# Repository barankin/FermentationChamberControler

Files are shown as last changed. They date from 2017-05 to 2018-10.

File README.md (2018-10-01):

# Fermentation Chamber Controller
arduino based fermentation chamber temperature controller

* Stage one including:
 * Arduino Nano
 * 1602 LCD display
 * Rotary encoder for changing temperature
 * Two temperature probes DS18B20 using one wire bus
 * Relay for turning compressor on and off
 * Relay for turning heater on and off
* Stage two including:
 * Logging using ESP-01 and Ai Thinker commands over hardware serial
* Stage three including:
 * Full control and status via ESP-01

# Background
* The LCD circuit for the LCD HelloWorld. We will use the same pin configuration:
 * LCD RS pin to digital pin 12
 * LCD Enable pin to digital pin 11
 * LCD D4 pin to digital pin 5
 * LCD D5 pin to digital pin 4
 * LCD D6 pin to digital pin 3
 * LCD D7 pin to digital pin 2
 * LCD R/W pin to ground
 * LCD VSS pin to ground
 * LCD VCC pin to 5V
 * 10K resistor:
 * ends to +5V and ground
 * wiper to LCD VO pin (pin 3)

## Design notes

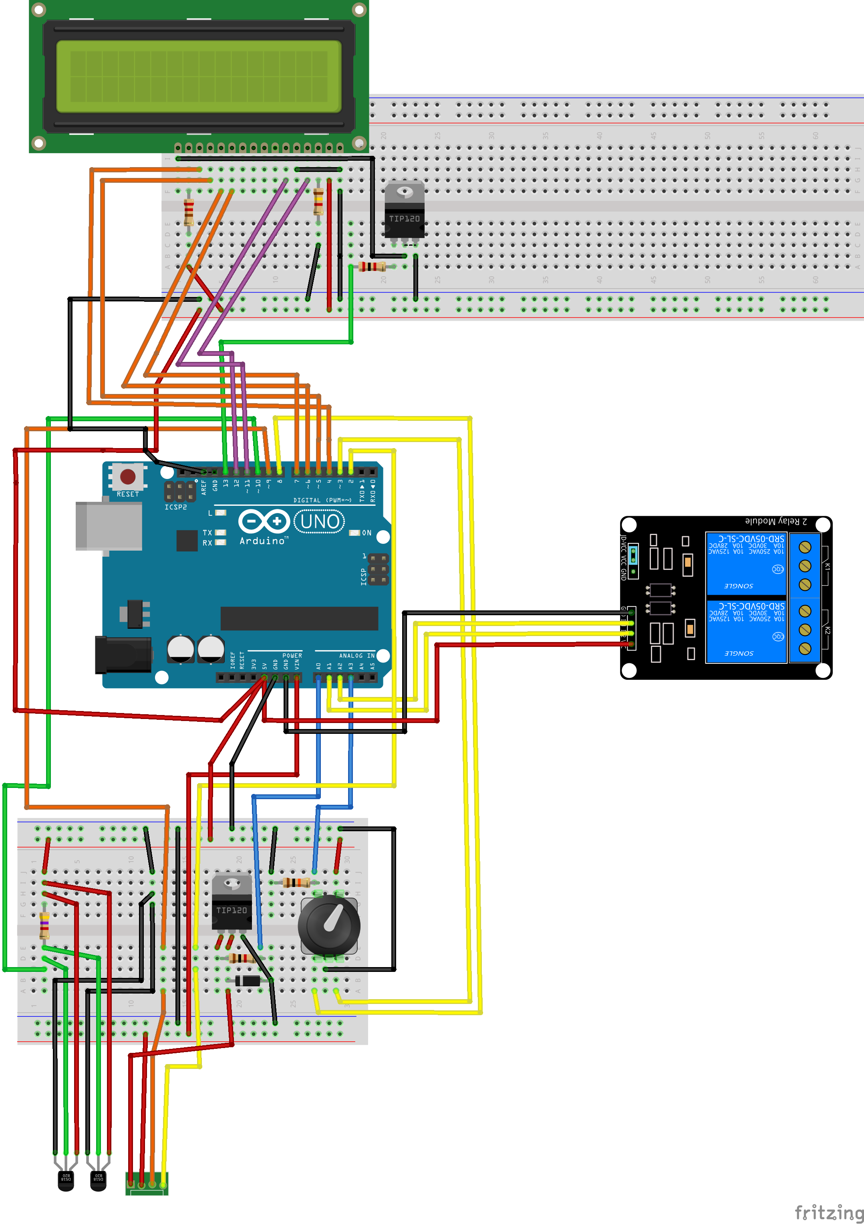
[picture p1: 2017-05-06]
FermentationChamberController_bb.png

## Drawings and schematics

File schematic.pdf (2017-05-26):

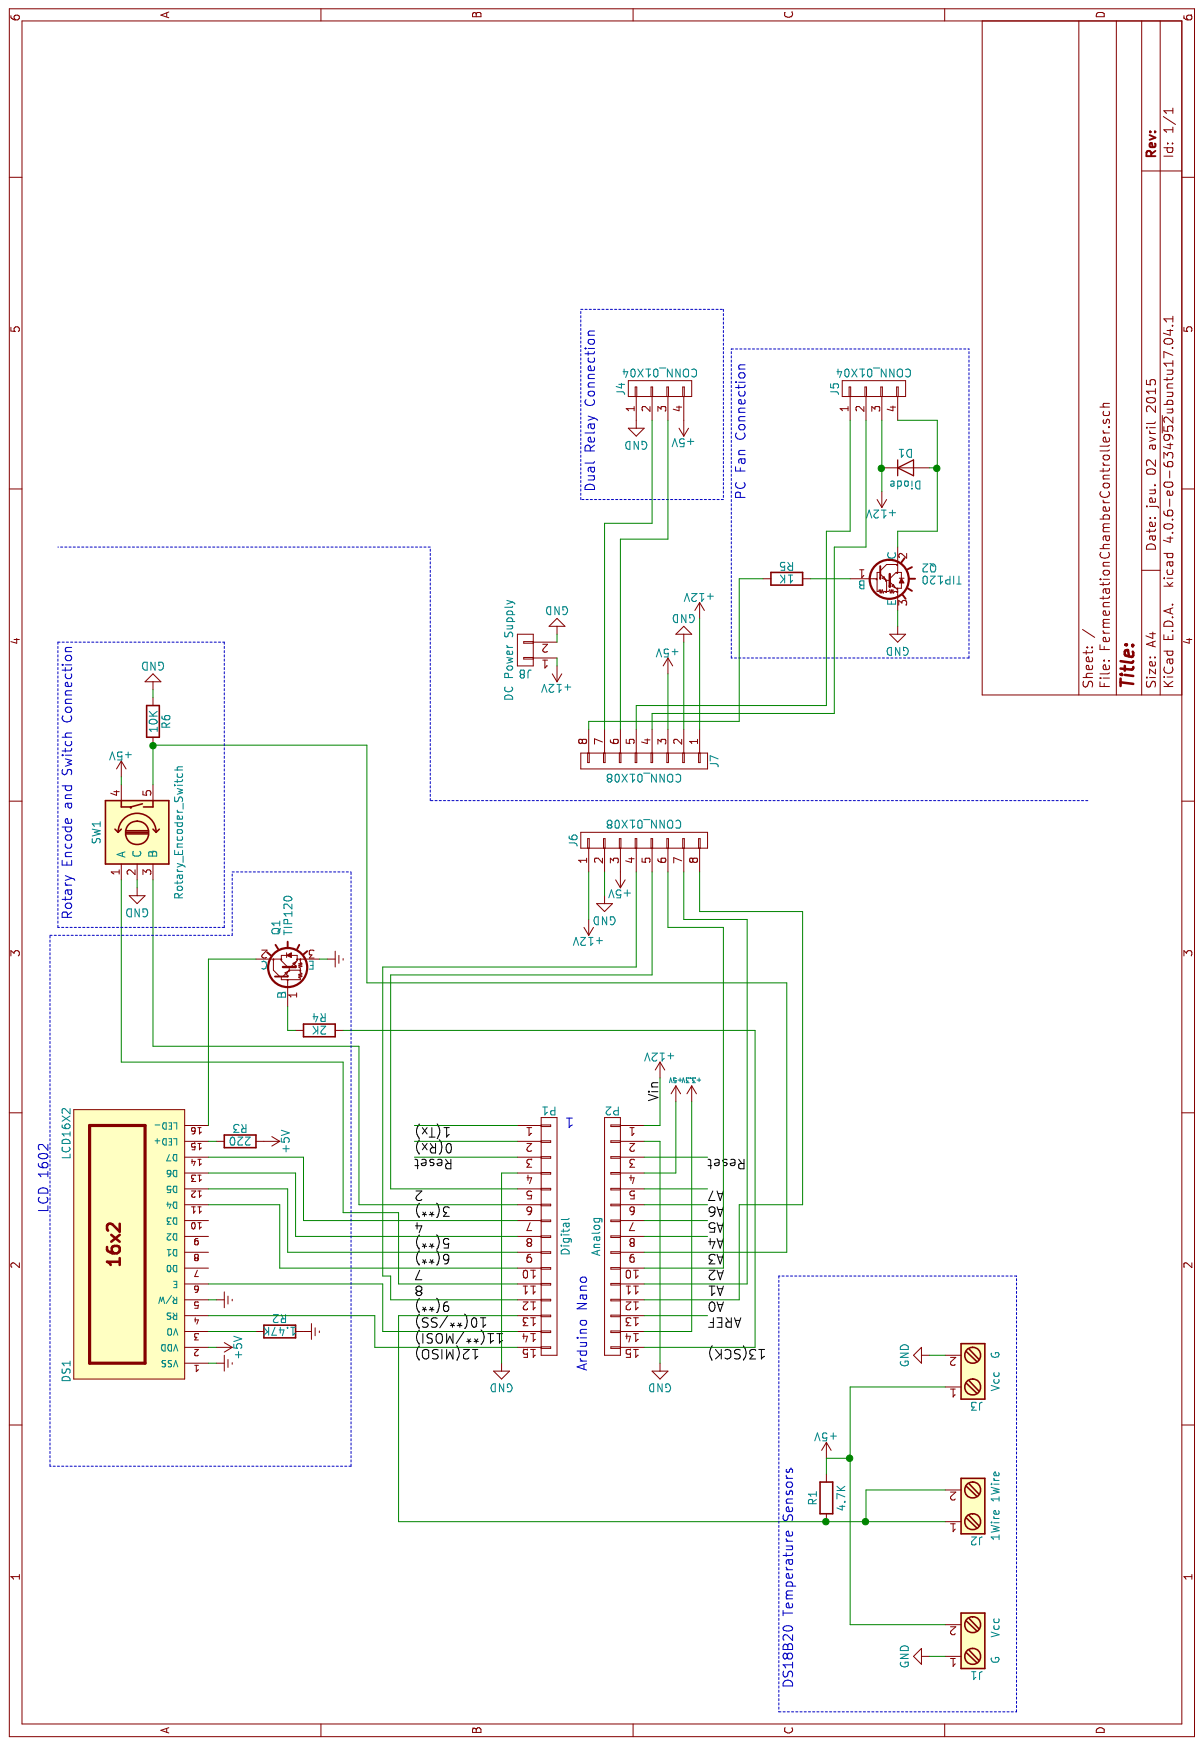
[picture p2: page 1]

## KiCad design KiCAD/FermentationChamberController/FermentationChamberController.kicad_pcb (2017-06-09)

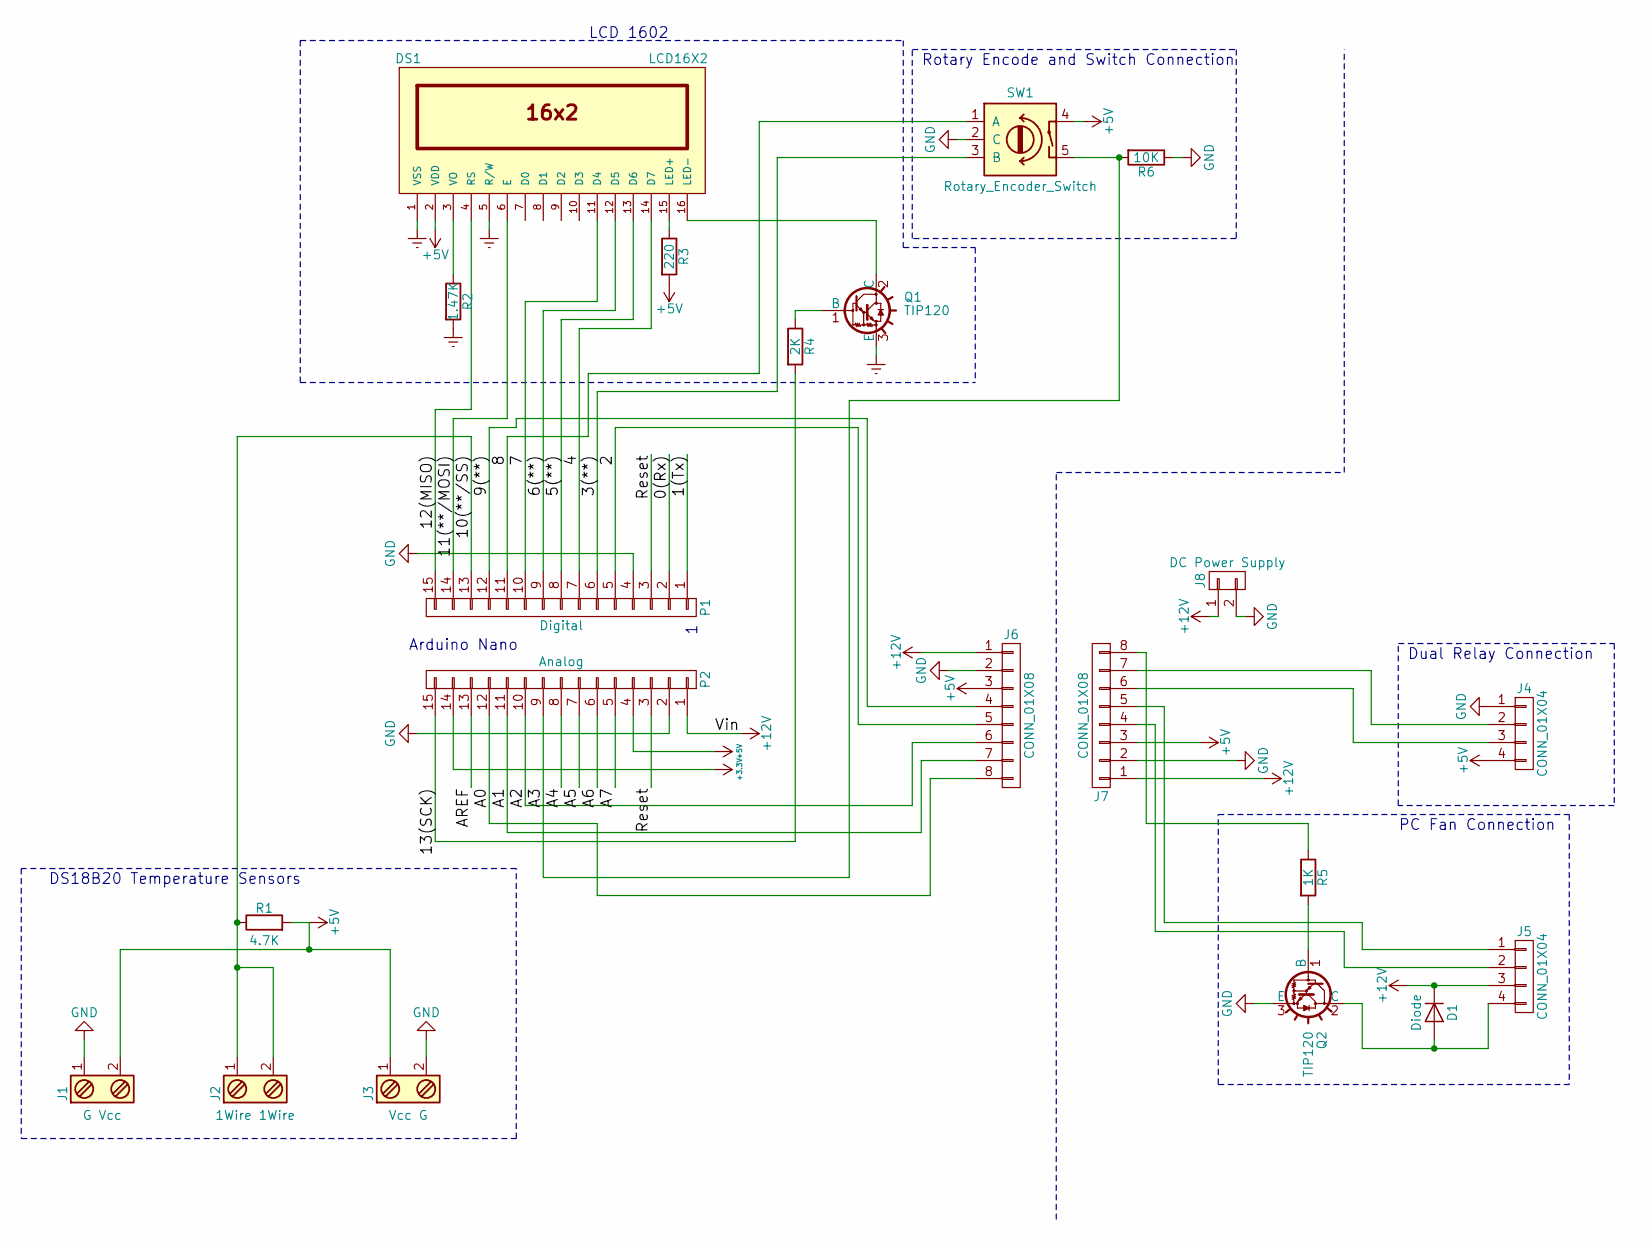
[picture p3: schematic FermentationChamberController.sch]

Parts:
D1: Diode; D_DO-15_P10.16mm_Horizontal
DS1: LCD16X2; Pin_Header_Straight_1x16_Pitch2.54mm
J1: G Vcc; bornier2
J2: 1Wire 1Wire; bornier2
J3: Vcc G; bornier2
J4, J5: CONN_01X04; Pin_Header_Straight_1x04_Pitch2.54mm
J6, J7: CONN_01X08; RJ45_8
J8: DC Power Supply; Pin_Header_Straight_1x02_Pitch1.27mm
P1: Digital; Pin_Header_Straight_1x15_Pitch2.54mm
P2: Analog; Pin_Header_Straight_1x15_Pitch2.54mm
Q1: TIP120; TO-220_Horizontal
Q2: TIP120; TO-220_Vertical
R1: 4.7K; R_Axial_DIN0207_L6.3mm_D2.5mm_P10.16mm_Horizontal
R2: 1.47K; R_Axial_DIN0207_L6.3mm_D2.5mm_P10.16mm_Horizontal
R3: 220; R_Axial_DIN0207_L6.3mm_D2.5mm_P10.16mm_Horizontal
R4: 2K; R_Axial_DIN0207_L6.3mm_D2.5mm_P10.16mm_Horizontal
R5: 1K; R_Axial_DIN0207_L6.3mm_D2.5mm_P10.16mm_Horizontal
R6: 10K; R_Axial_DIN0207_L6.3mm_D2.5mm_P10.16mm_Horizontal
SW1: Rotary_Encoder_Switch; Pin_Header_Straight_1x05_Pitch2.54mm

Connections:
+3V3: P2.14
+5V: DS1.2 (VDD), J1.2, J3.1, J4.4, J6.3, J7.3, P2.4, R1.2, R3.2, SW1.4
+12V: D1.1 (K), J5.3, J6.1, J7.1, J8.1, P2.1
/0(Rx): P1.2
/1(Tx): P1.1
/2: J6.5, P1.5
/3(**): P1.6, SW1.3 (B)
/4: DS1.14 (D7), P1.7
/5(**): DS1.13 (D6), P1.8
/6(**): DS1.12 (D5), P1.9
/7: DS1.11 (D4), P1.10
/8: P1.11, SW1.1 (A)
/9(**): J6.4, P1.12
/10(**/SS): J2.1, J2.2, P1.13, R1.1
/11(**/MOSI): DS1.6 (E), P1.14
/12(MISO): DS1.4 (RS), P1.15
/13(SCK): P2.15, R4.2
/A0: J6.8, P2.12
/A1: J6.7, P2.11
/A2: J6.6, P2.10
/A3: P2.9, R6.2, SW1.5
/A4: P2.8
/A5: P2.7
/A6: P2.6
/A7: P2.5
/AREF: P2.13
/Reset: P1.3, P2.3
Earth: DS1.1 (VSS), DS1.5 (R/W), Q1.3 (E), R2.2
GND: J1.1, J3.2, J4.1, J6.2, J7.2, J8.2, P1.4, P2.2, Q2.3 (E), R6.1, SW1.2 (C)
unnamed: D1.2 (A), J5.4, Q2.2 (C)
unnamed: DS1.3 (VO), R2.1
unnamed: DS1.15 (LED+), R3.1
unnamed: DS1.16 (LED-), Q1.2 (C)
unnamed: J4.2, J7.7
unnamed: J4.3, J7.6
unnamed: J5.1, J7.5
unnamed: J5.2, J7.4
unnamed: J7.8, R5.1
unnamed: Q1.1 (B), R4.1
unnamed: Q2.1 (B), R5.2

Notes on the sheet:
LCD 1602
DS18B20 Temperature Sensors
PC Fan Connection
Dual Relay Connection
Rotary Encode and Switch Connection
Arduino Nano

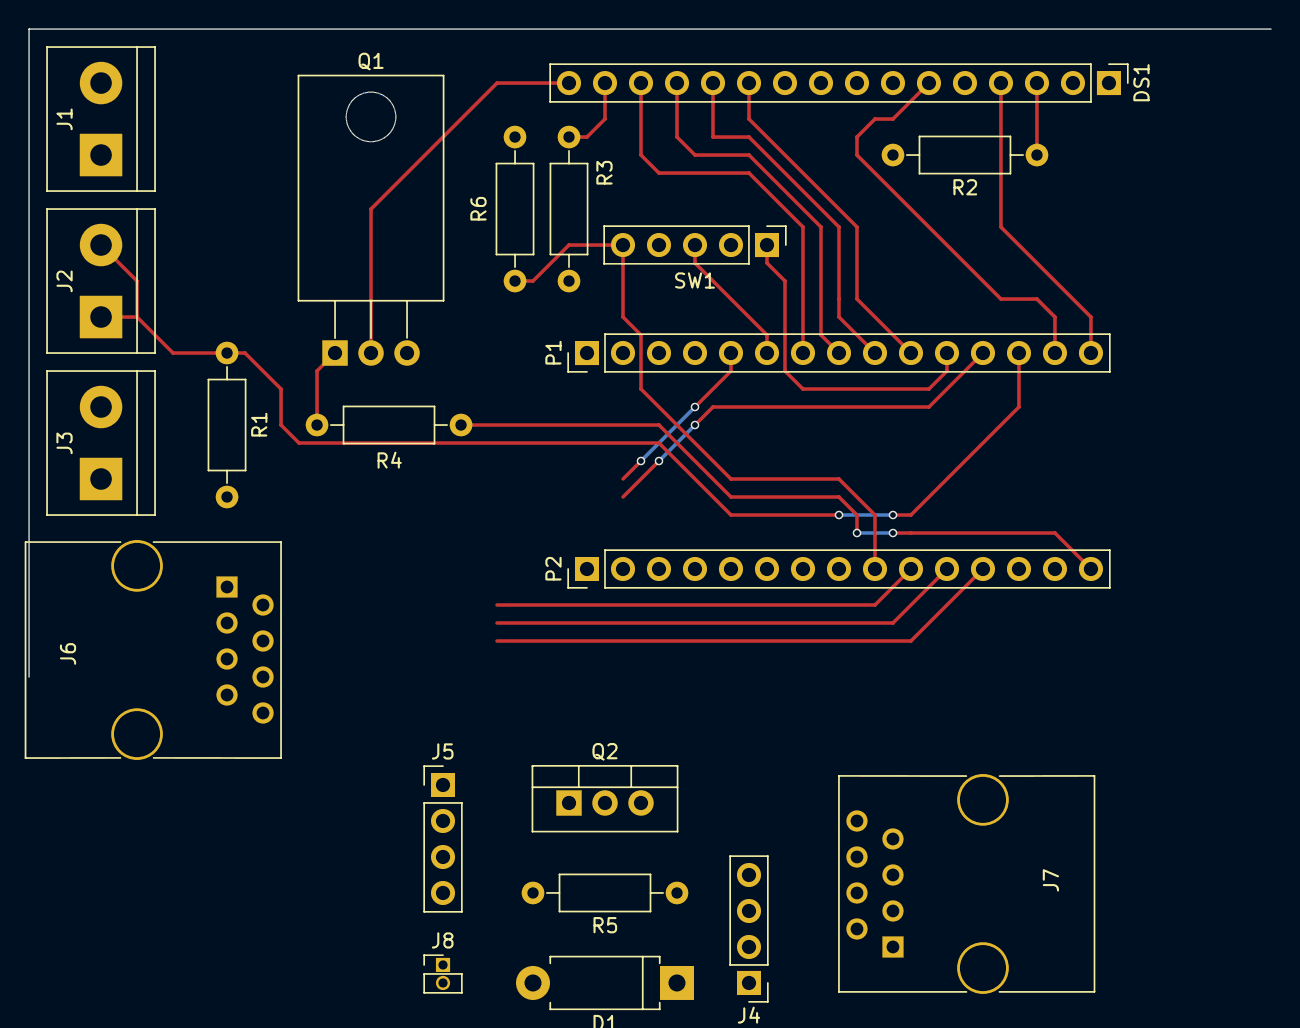
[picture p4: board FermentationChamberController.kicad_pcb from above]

Board: 2 copper layers, 21 parts (0 on the bottom side), 32 nets.

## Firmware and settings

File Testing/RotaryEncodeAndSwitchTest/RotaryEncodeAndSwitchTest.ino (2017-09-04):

/*
  The circuit:
   LCD RS pin to digital pin 12
   LCD Enable pin to digital pin 11
   LCD D4 pin to digital pin 7
   LCD D5 pin to digital pin 6
   LCD D6 pin to digital pin 5
   LCD D7 pin to digital pin 4
   LCD R/W pin to ground
   LCD VSS pin to ground
   LCD VCC pin to 5V
   10K resistor:
   ends to +5V and ground
   wiper to LCD VO pin (pin 3)

*/

// include the library code:
#include <LiquidCrystal.h>
#include <Encoder.h>

//rotary encoder pins
#define Rotary_Encoder_Pin_A 8
#define Rotary_Encoder_Pin_B 3
#define encoderButtonPin A3    // the number of the pushbutton pin

#define LCDBacklightOnPin 13 //via TIP120 darlington

//Switch Variables
int encoderButtonState = LOW;
int reading;
int previous = HIGH;
int lastEncoderButtonState = LOW;
long time = 0;
long debounce = 200;

//Encoder Variables
long encoder0Pos = 0;

//Temperature Value
const float defaultSetTemp = 20.0f;
float setTempC = defaultSetTemp;
float maxTempC = 30.0f, minTempC = 2.0f;

// initialize the library with the numbers of the interface pins
LiquidCrystal lcd(12, 11, 7, 6, 5, 4);
Encoder knob(Rotary_Encoder_Pin_B, Rotary_Encoder_Pin_A);

void setup() {
  pinMode(LCDBacklightOnPin, OUTPUT);
  digitalWrite(LCDBacklightOnPin, LOW);
  pinMode(encoderButtonPin, INPUT);
  Serial.begin(9600);
  Serial.println("Serial is working");
  // set up the LCD's number of columns and rows:
  lcd.begin(16, 2);
  // Print a message to the LCD.
  lcd.print("Set ");lcd.print((char)223);lcd.print("C:");
  lcd.setCursor(8, 0);
  lcd.print(setTempC);
  Serial.println(setTempC);
}

void loop() {
  reading = digitalRead(encoderButtonPin);
  if (reading == HIGH && previous == LOW && millis() - time > debounce) {
    if (encoderButtonState == HIGH)
      encoderButtonState = LOW;
    else
      encoderButtonState = HIGH;

    time = millis();
  }
  previous = reading;

  // set the cursor to column 0, line 1
  // (note: line 1 is the second row, since counting begins with 0):
  lcd.setCursor(0, 1);
  // print the number of seconds since reset:
  if (encoderButtonState == HIGH && encoderButtonState != lastEncoderButtonState) {
    digitalWrite(LCDBacklightOnPin, HIGH);
    Serial.println("on");
    encoder0Pos = knob.read();
  } else if (encoderButtonState == LOW && encoderButtonState != lastEncoderButtonState) {
    digitalWrite(LCDBacklightOnPin, LOW);
    Serial.println("off");
  }
  if (encoderButtonState == HIGH) {
    long newPosition;
    newPosition = knob.read();
    if (newPosition != encoder0Pos) {
      float positionDifference = newPosition - encoder0Pos;
      encoder0Pos = newPosition;
      setTempC += positionDifference / 50;
      Serial.println(setTempC);

      lcd.setCursor(8, 0);
      lcd.print(setTempC);
    }
  }
  lastEncoderButtonState = encoderButtonState;
}

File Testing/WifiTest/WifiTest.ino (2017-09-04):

#include <SoftwareSerial.h>
//#include <string.h>
#define TIMEOUT 5000 // mS
#define LED 5

#define encoderButtonPin A3    // the number of the pushbutton pin
#define LCDBacklightOnPin 13 //via TIP120 darlington

#define SSID "ford_prefect_2.4"
#define PASS "annabanana"
#define IP "184.106.153.149" // thingspeak.com
String GET = "GET /update?key=WTYK34F502K75NFE";

SoftwareSerial mySerial(A5, A4); // RX, TX


//Switch Variables
int encoderButtonState = LOW;
int lastEncoderButtonState = LOW;
long time = 0;
long debounce = 200;


void setup()
{
  pinMode(LCDBacklightOnPin, OUTPUT);
  digitalWrite(LCDBacklightOnPin, LOW);
  pinMode(encoderButtonPin, INPUT);


  Serial.begin(9600);
  mySerial.begin(9600);
  Serial.println("Ready to go");
  SendCommand("AT+RST", "Ready");
  delay(5000);
  SendCommand("AT+CWMODE=1", "OK");
  SendCommand("AT+CIFSR", "OK");
  SendCommand("AT+CIPMUX=1", "OK");
  SendCommand("AT+CIPSERVER=1,80", "OK");
}

void loop() {
  /*if (mySerial.available())
    Serial.write(mySerial.read());
    if (Serial.available())
    mySerial.write(Serial.read());*/

  encoderButtonState = digitalRead(encoderButtonPin);

  if (encoderButtonState == HIGH) {
    /*mySerial.println("AT+CIPSEND=0,28");
      mySerial.println("<h1>Button was pressed!</h1>");
      delay(1000);
      SendCommand("AT+CIPCLOSE=0","OK");*/
    Serial.println("Button Pressed");
    updateTemp("0", "20", "22", "21",
               "0", "False", "False");
  }

  /******************************/
  //Buttons
  /*if (encoderButtonState == HIGH && encoderButtonState != lastEncoderButtonState) {
    digitalWrite(LCDBacklightOnPin, HIGH);
    Serial.println("on");
    encoder0Pos = knob.read();
    } else if (encoderButtonState == LOW && encoderButtonState != lastEncoderButtonState) {
    digitalWrite(LCDBacklightOnPin, LOW);
    Serial.println("off");
    }*/

  /******************************/

  String IncomingString = "";
  boolean StringReady = false;

  while (mySerial.available()) {
    IncomingString = mySerial.readString();
    StringReady = true;

  }

  if (StringReady) {
    //Serial.println("Received String: " + IncomingString);

    if (IncomingString.indexOf("LED=ON") != -1) {
      digitalWrite(LCDBacklightOnPin, HIGH);
      Serial.println("LED=ON");
    }

    if (IncomingString.indexOf("LED=OFF") != -1) {
      digitalWrite(LCDBacklightOnPin, LOW);
      Serial.println("LED=OFF");
    }

  }

}

boolean SendCommand(String cmd, String ack) {
  mySerial.println(cmd); // Send "AT+" command to module
  if (!echoFind(ack)) // timed out waiting for ack string
    return true; // ack blank or ack found
}

boolean echoFind(String keyword) {
  byte current_char = 0;
  byte keyword_length = keyword.length();
  long deadline = millis() + TIMEOUT;
  while (millis() < deadline) {
    if (mySerial.available()) {
      char ch = mySerial.read();
      Serial.write(ch);
      if (ch == keyword[current_char])
        if (++current_char == keyword_length) {
          Serial.println();
          return true;

        }

    }

  }
  return false; // Timed out
}

void updateTemp(String tenmp1, String temp2, String tempAvg,
                String tempInternal, String heaterOn, String compressorOn) {

  String cmd = "AT+CIPSTART=\"TCP\",\"";
  cmd += IP;
  cmd += "\",80";

  Serial.println(cmd);
  mySerial.println(cmd);
  delay(2000);
  if (mySerial.find("Error")) {
    Serial.println("Error");
    return;
  }
  cmd = GET;
  cmd += "&field1=";
  cmd += currenttime;
  cmd += "&field2=";
  cmd += tenmp1;
  cmd += "&field3=";
  cmd += temp2;
  cmd += "&field4=";
  cmd += tempAvg;
  cmd += "&field5=";
  cmd += tempInternal;
  cmd += "&field6=";
  cmd += heaterOn;
  cmd += "&field7=";
  cmd += compressorOn;
  cmd += "\r\n";
  mySerial.print("AT+CIPSEND=");
  mySerial.println(cmd.length());
  mySerial.print(cmd);
  Serial.println(cmd);
  mySerial.println("AT+CIPCLOSE");

}

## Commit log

2017-02-09 Started building the loop. Added temperature detection every 5 seconds.
2017-02-09 Preliminary implementation of fan code
2017-02-09 Minor refinement to fan interval
2017-03-12 Adding Fritzing File
    Added a WIP fritzing file
    [FermentationChamberController.fzz]
2017-03-17 Add Fritzing File
    [FermentationChamberController.fzz]
2017-03-19 Updated Rotatry encode and Fan
    Updated based on testing done with rotary encode and fan speed for a 4 wire fan (PWM controlled).
2017-03-31 Improving Fritzign file
    Getting it more complete and better organized visually.
    [FermentationChamberController.fzz]
2017-04-22 Progress
    added rotary encode switch
    [FermentationChamberController.fzz]
2017-04-22 Added diod to fan control drawing
    [FermentationChamberController.fzz]
2017-05-05 Started to add test programs
    [FermentationChamberController.fzz]
2017-05-06 Updated rotary encoder wiring
    [FermentationChamberController.fzz]
2017-05-06 Updated LCD wiring
    Changed power from VCC to pin 13 so that the display can be turned on and off.
    [FermentationChamberController.fzz]
2017-05-06 Added TIP120 to switch on LCD
    [FermentationChamberController.fzz]
2017-05-06 modified TIP120 to only swith LCD backlight
    [FermentationChamberController.fzz]
2017-05-16 Created KiCAD File and began schematic with the Arduino and LCD 1602 circuit.
    [FermentationChamberController.kicad_pcb, FermentationChamberController.sch]
2017-05-16 Minor updates to lcd schematic
    [FermentationChamberController.sch]
2017-05-17 Added test suites
    Test sutie for one wire bus and temperature measurement
    [FermentationChamberController.fzz]
2017-05-17 Basic schematic complete per Fritzing file
    [FermentationChamberController.sch]
2017-05-17 Minor schematic fixes (fan diode)
    [FermentationChamberController.sch]
2017-05-17 And another correction to the diode
    [FermentationChamberController.sch]
2017-05-17 Created KiCAD netlist
2017-05-18 Workign on the PCB Layout, first step.
    [FermentationChamberController.kicad_pcb, FermentationChamberController.sch]
2017-05-18 Updated header styles for the arduino, fan and relay connectors.
    [FermentationChamberController.kicad_pcb]
2017-05-18 Updated readme to state arduino nano
    Arduino Uno board is used in the Fritzing file but the actual build will use a Nano.
2017-05-19 Updated PCB layour
    almost done.... maybe
    [FermentationChamberController.fzz, FermentationChamberController.kicad_pcb, FermentationChamberController.sch]
2017-05-26 Updated schematic to split into two pcbs
    [FermentationChamberController.sch]
2017-06-09 Updates to Kicad and testing
    RJ 45 connectors
    bad test for wifi...
    [FermentationChamberController.kicad_pcb, FermentationChamberController.sch]
2017-08-06 Added Fan Test
    [FermentationChamberController.sch]
2017-08-06 Temp test updates and corrections
    Trouble shooting circuit
    [FanTest.ino, FermentationChamberController.ino]
2017-08-27 Fan working (except rpm measure)
2017-09-04 wifitest2
    crashing on tcp connection
    [RotaryEncodeAndSwitchTest.ino, WifiTest-WeeESP8266.ino, WifiTest.ino]
2017-09-04 wifiupload working
    Apparently i was running out of memory. 1k is too large a buffer to receive the web data! commented out all receipt of web data
    [WifiTest-WeeESP8266.ino]
2017-10-09 RelayTest Added
2017-10-09 Fixed relay to be normally open
    Originally, I was starting the heater and compressor automatically. Now, they are always off unless turned on.... much better
    [RelayTest.ino]
